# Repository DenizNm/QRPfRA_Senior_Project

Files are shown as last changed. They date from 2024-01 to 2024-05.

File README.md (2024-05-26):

# QRPfRA: Quadruped Robot Platform for Research Applications

## About the Project
This project develops a low-cost, modular quadruped robot to enhance accessibility to robotics education and research. Leveraging the open-source SpotMicro design, the robot is engineered with three degrees of freedom per leg, using readily available servo motors and a Raspberry Pi 4B for computation. It incorporates a 9-DoF IMU and a Raspberry Pi camera for environmental sensing and navigation. The control and processing software, built in Python, utilizes TensorFlow/TFLite and OpenCV for tasks such as motion planning and image processing.

## Features
- **Cost-Effective Design:** Utilizes off-the-shelf components to maintain affordability.
- **Modular and Scalable:** Easy to modify and extend, perfect for educational purposes.
- **Interdisciplinary Approach:** Combines mechanical, electrical, and computer engineering.

## Table of Contents
- [Contact](#contact)
- [Acknowledgements](#acknowledgements)

## Contact
Deniz Namlısesli - [deniz.namlisesli@std.yeditepe.edu.tr](mailto:deniz.namlisesli@std.yeditepe.edu.tr)

Project Link: [https://github.com/DenizNm/QRPfRA_Senior_Project](https://github.com/DenizNm/QRPfRA_Senior_Project)

## Acknowledgements
- [SpotMicro Community](https://spotmicroai.readthedocs.io)
- [TensorFlow](https://tensorflow.org)
- [OpenCV](https://opencv.org)
- All other libraries and frameworks used in this project are acknowledged in the project documentation.

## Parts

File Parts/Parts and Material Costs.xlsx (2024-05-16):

Part | Piece(s) | Total Cost
Raspberry Pi 4B - 8Gb | 1 | ₺2958.75
Raspberry Pi Camera Module 3 | 1 | ₺889.93
MG996R Servo | 12 | ₺882.40
1Kg PLA+ 3D Printer Filament | 1 | ₺445.26
Adafruit BNO055 9-DOF IMU | 1 | ₺1577.56
Custom Designed PCB | 5 | ₺374.92
TAIYO YUDEN TMK316BJ106ML-T Cap, 10Âµf, 25V, 20%, X5r, 1206 | 10 | ₺48.61
TAIYO YUDEN TMK316BBJ226ML-T Capacitor, Mlcc, X5r, 22Uf, 25V, 1206 | 12 | ₺127.37
KEMET C0603C104M5RACTU Cap, 0.1Âµf, 50V, 20%, X7r, 0603 | 10 | ₺8.47
WALSIN WR06X104 JTL Res, 100K, 5%, 0.1W, 0603, Thick Film | 10 | ₺2.22
VISHAY CRCW060352K3FKEA. Res, 52K3, 1%, 0.1W, 0603, Thick Film | 10 | ₺10.70
BOURNS CR0603-FX-1002ELF Res, 10K, 1%, 0.1W, 0603, Thick Film | 10 | ₺4.01
MULTICOMP PRO MCWR06X102 JTL Res, 1K, 5%, 0.1W, 0603, Thick Film | 10 | ₺2.27
TDK VLS6045EX-3R3N Inductor, 3.3Uh, 4.95A, 30%, Wirewound | 5 | ₺70.51
Diodes Inc AP62300Z6-7 DcDc Conv Sync Buck 750Khz 85Deg C | 10 | ₺127.32
Multicomp Pro MP008288 Led Green 90Mcd 577Nm 0603 | 5 | ₺19.40
Multicomp Pro MP011984 Tb Wire To Brd RA 2Way 18Awg | 5 | ₺47.63
Raspberry Pi 2x20 Header Pin | 1 | ₺43.16
1x40 180 Degree Female Header | 1 | ₺5.49
21700 Li-Ion Battery | 3 | ₺960.00
3S 60A BMS | 1 | ₺231.95
 | Total | ₺8837.94

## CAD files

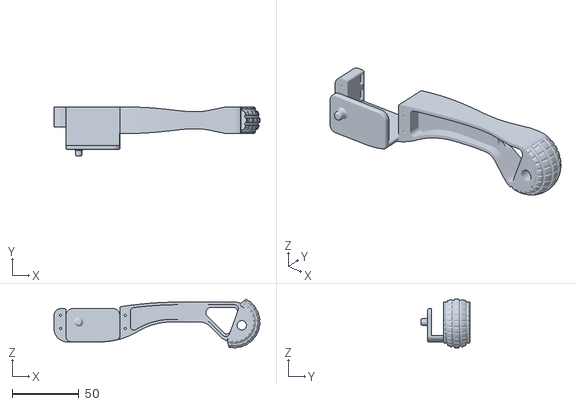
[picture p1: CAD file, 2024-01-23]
QRPfRA/origninal_parts/right_wrist.stl
154.7 x 36.9 x 36.6

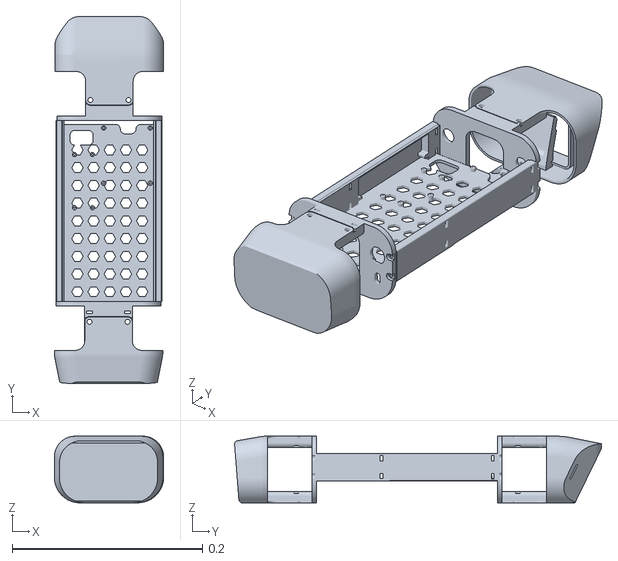
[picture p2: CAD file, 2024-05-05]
QRPfRA/QRPfRA_body_m_extended.stl
0.115 x 0.386 x 0.0701

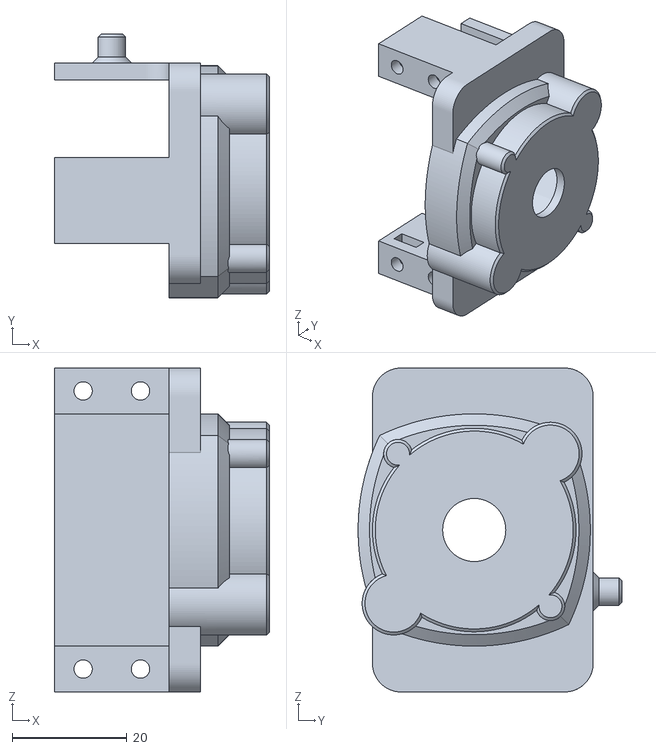
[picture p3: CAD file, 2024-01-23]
QRPfRA/origninal_parts/right_hindlimb.stl
37.5 x 46.0 x 56.5

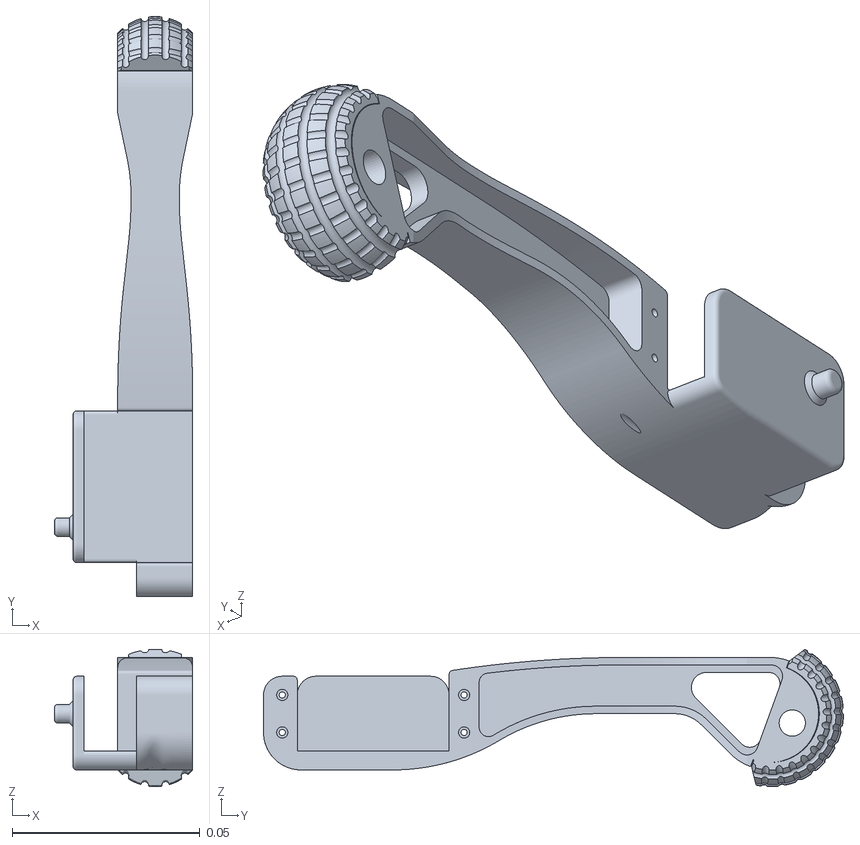
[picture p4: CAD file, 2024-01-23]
QRPfRA/QRPfRA_left_wrist_m.stl
0.0369 x 0.155 x 0.0366

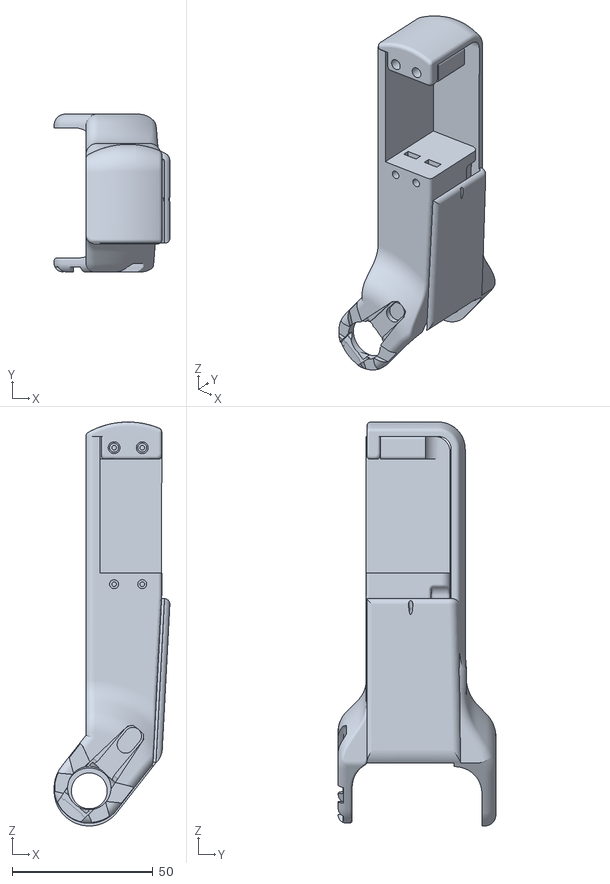
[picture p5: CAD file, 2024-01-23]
QRPfRA/origninal_parts/right_midlimb.stl
41.1 x 56.1 x 143.6

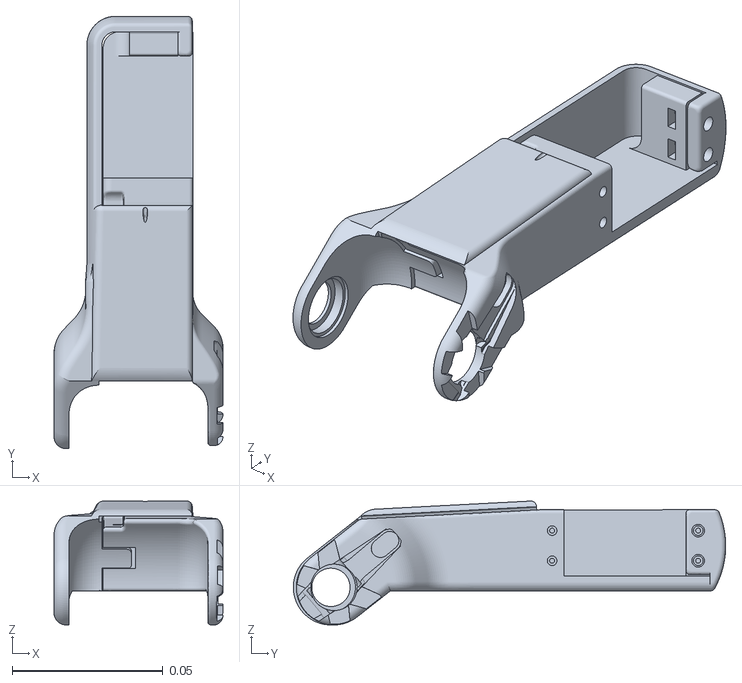
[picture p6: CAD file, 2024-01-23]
QRPfRA/QRPfRA_left_midlimb_m.stl
0.0561 x 0.144 x 0.0411

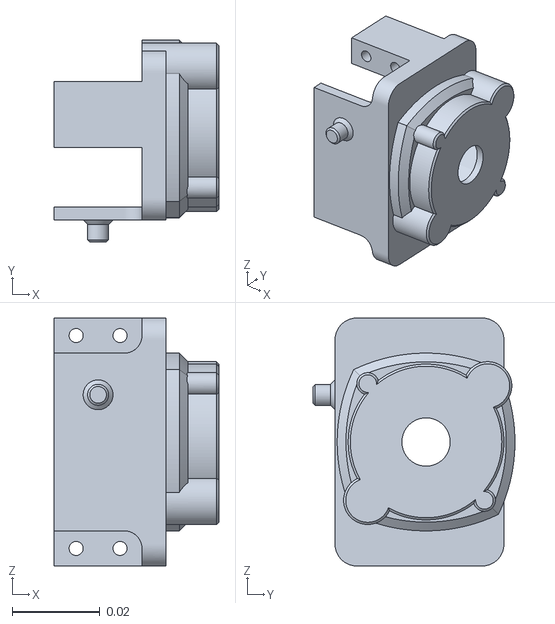
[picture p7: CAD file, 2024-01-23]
QRPfRA/QRPfRA_right_hindlimb_m.stl
0.0375 x 0.046 x 0.0565

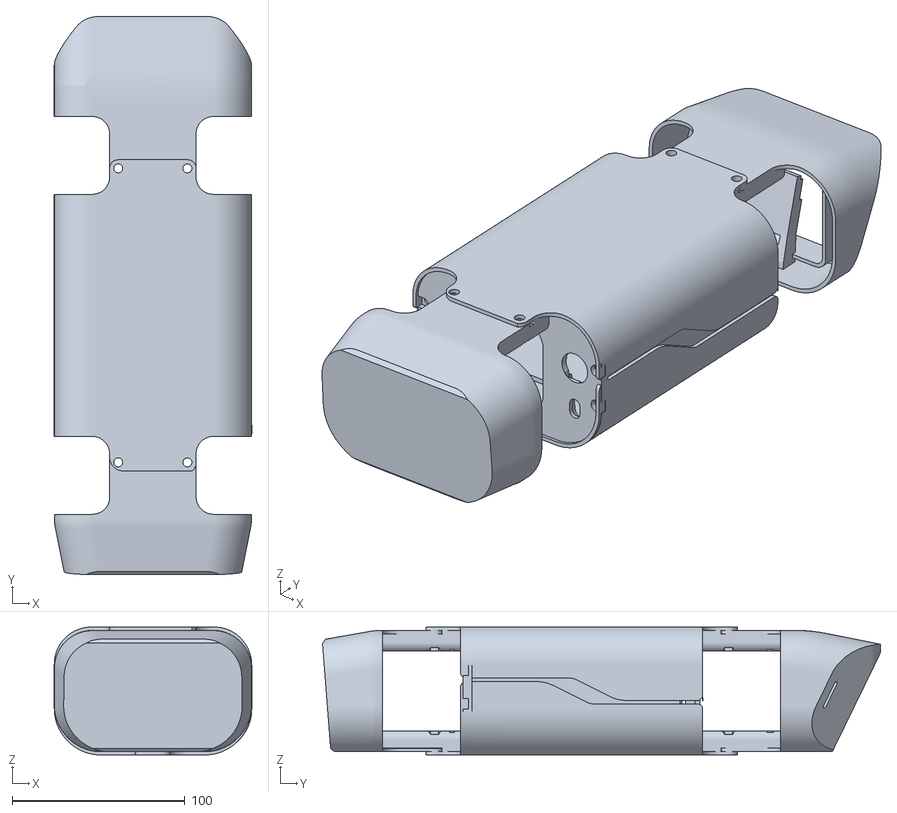
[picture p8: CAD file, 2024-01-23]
QRPfRA/origninal_parts/Body1.stl
114.2 x 322.6 x 74.0

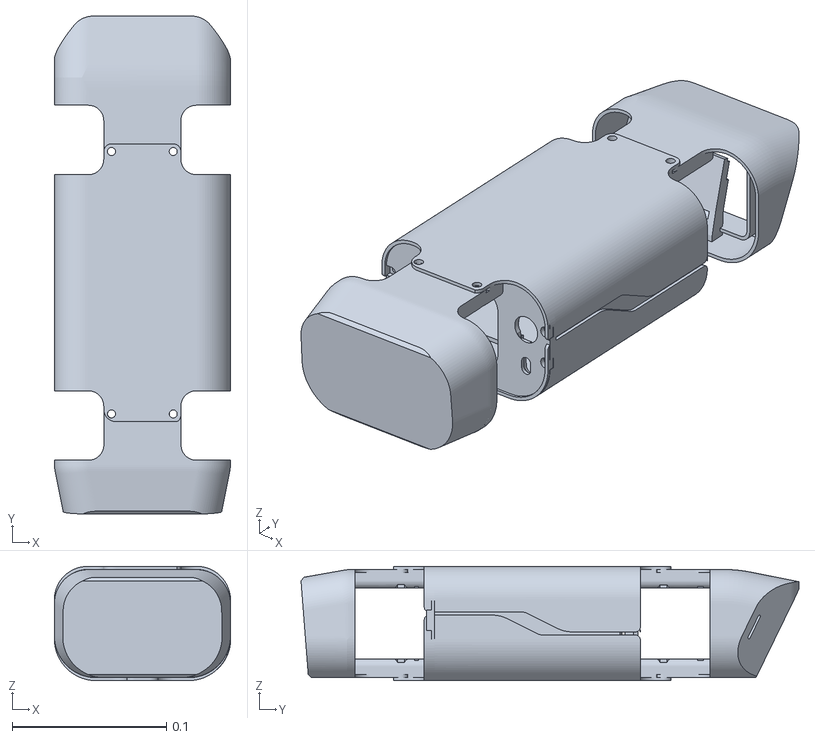
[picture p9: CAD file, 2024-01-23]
QRPfRA/QRPfRA_body_m.stl
0.114 x 0.323 x 0.074

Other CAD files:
QRPfRA/origninal_parts/left_wrist.stl
QRPfRA/origninal_parts/left_hindlimb.stl
QRPfRA/QRPfRA_right_midlimb_m.stl
QRPfRA/origninal_parts/left_midlimb.stl
QRPfRA/QRPfRA_left_hindlimb_m.stl
QRPfRA/QRPfRA_right_wrist_m.stl

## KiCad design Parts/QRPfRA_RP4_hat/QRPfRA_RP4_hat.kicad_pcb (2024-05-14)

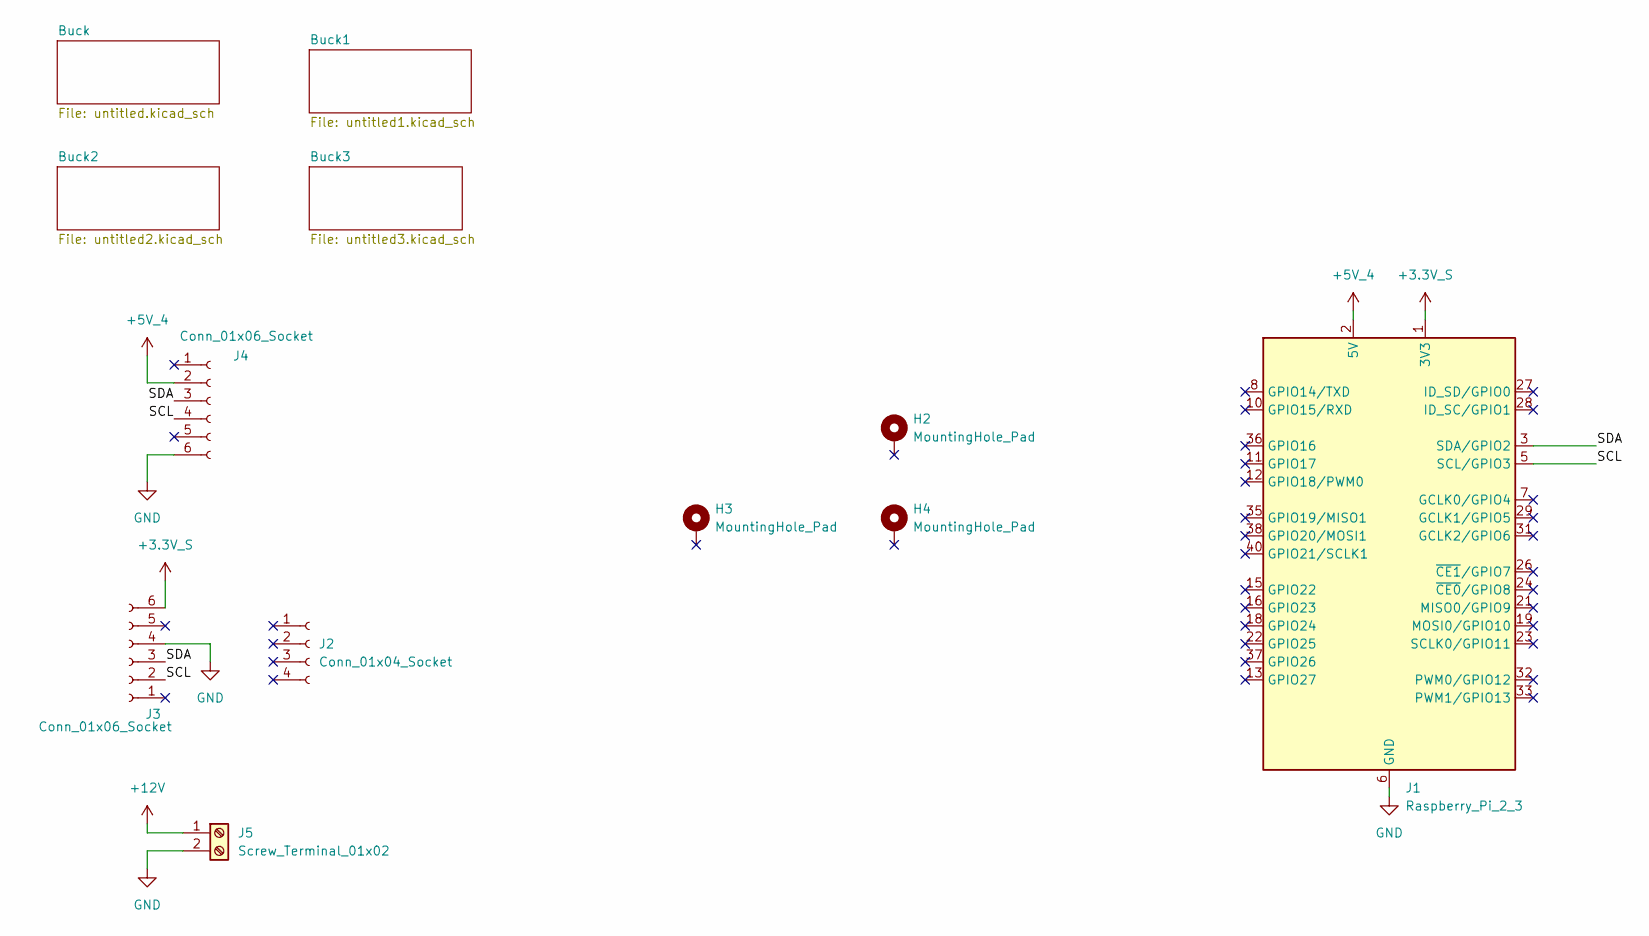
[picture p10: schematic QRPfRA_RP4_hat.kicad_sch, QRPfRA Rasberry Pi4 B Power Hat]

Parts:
H2, H3, H4: MountingHole_Pad; MountingHole_2.7mm_Pad
J1: Raspberry_Pi_2_3; PinHeader_2x20_P2.54mm_Vertical
J2: Conn_01x04_Socket; PinHeader_1x04_P2.54mm_Vertical
J3, J4: Conn_01x06_Socket; PinHeader_1x06_P2.54mm_Vertical
J5: Screw_Terminal_01x02; TerminalBlock_4Ucon_1x02_P3.50mm_Vertical

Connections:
+3.3V_S: J1.1 (3V3), J1.17 (3V3), J3.6
+5V_4: J1.2 (5V), J1.4 (5V), J4.2; also elsewhere on the board
+12V: J5.1; also elsewhere on the board
/SCL: J1.5 (SCL/GPIO3), J3.2, J4.4
/SDA: J1.3 (SDA/GPIO2), J3.3, J4.3
GND: J1.6 (GND), J1.9 (GND), J1.14 (GND), J1.20 (GND), J1.25 (GND), J1.30 (GND), J1.34 (GND), J1.39 (GND), J3.4, J4.6, J5.2; also elsewhere on the board

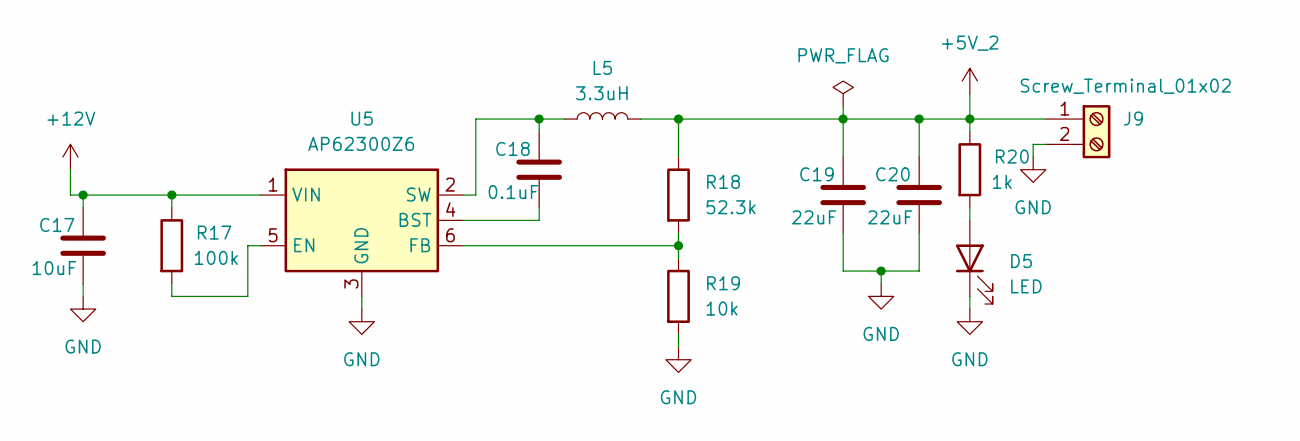
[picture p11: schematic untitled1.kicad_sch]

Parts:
C17: 10uF; C_1206_3216Metric
C18: 0.1uF; C_0603_1608Metric
C19, C20: 22uF; C_1206_3216Metric
D5: LED; LED_0603_1608Metric
J9: Screw_Terminal_01x02; TerminalBlock_4Ucon_1x02_P3.50mm_Vertical
L5: 3.3uH; L_TDK_VLS6045EX_VLS6045AF
R17: 100k; R_0603_1608Metric
R18: 52.3k; R_0603_1608Metric
R19: 10k; R_0603_1608Metric
R20: 1k; R_0603_1608Metric
U5: AP62300Z6; SOT-563

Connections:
+5V_2: C19.1, C20.1, J9.1, L5.2, R18.1, R20.1
+12V: C17.1, R17.1, U5.1 (VIN); also elsewhere on the board
GND: C17.2, C19.2, C20.2, D5.1 (K), J9.2, R19.2, U5.3 (GND); also elsewhere on the board
unnamed: D5.2 (A), R20.2
unnamed: C18.2, U5.4 (BST)
unnamed: R17.2, U5.5 (EN)
unnamed: R18.2, R19.1, U5.6 (FB)
unnamed: C18.1, L5.1, U5.2 (SW)

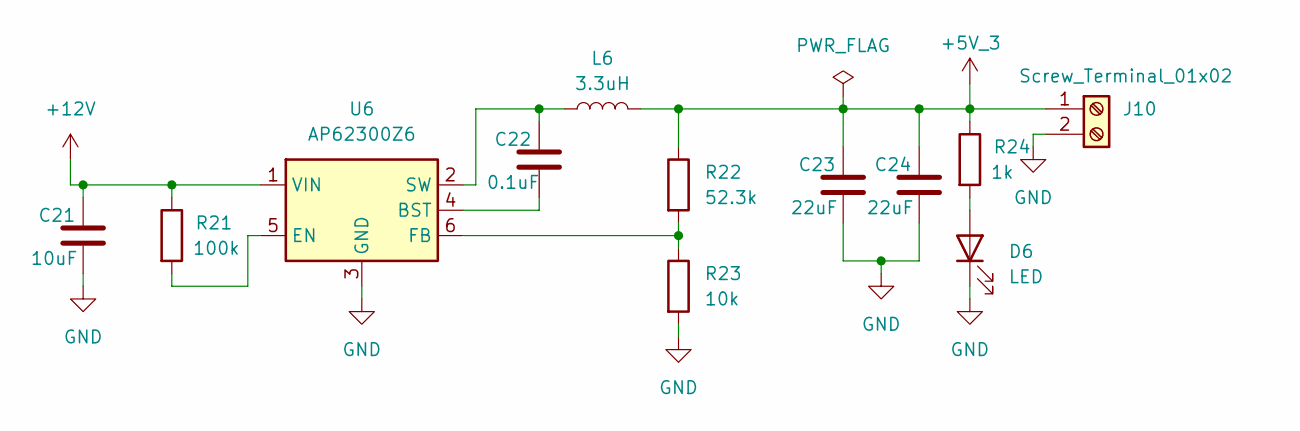
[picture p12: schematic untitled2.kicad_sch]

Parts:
C21: 10uF; C_1206_3216Metric
C22: 0.1uF; C_0603_1608Metric
C23, C24: 22uF; C_1206_3216Metric
D6: LED; LED_0603_1608Metric
J10: Screw_Terminal_01x02; TerminalBlock_4Ucon_1x02_P3.50mm_Vertical
L6: 3.3uH; L_TDK_VLS6045EX_VLS6045AF
R21: 100k; R_0603_1608Metric
R22: 52.3k; R_0603_1608Metric
R23: 10k; R_0603_1608Metric
R24: 1k; R_0603_1608Metric
U6: AP62300Z6; SOT-563

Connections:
+5V_3: C23.1, C24.1, J10.1, L6.2, R22.1, R24.1
+12V: C21.1, R21.1, U6.1 (VIN); also elsewhere on the board
GND: C21.2, C23.2, C24.2, D6.1 (K), J10.2, R23.2, U6.3 (GND); also elsewhere on the board
unnamed: D6.2 (A), R24.2
unnamed: C22.2, U6.4 (BST)
unnamed: R21.2, U6.5 (EN)
unnamed: R22.2, R23.1, U6.6 (FB)
unnamed: C22.1, L6.1, U6.2 (SW)

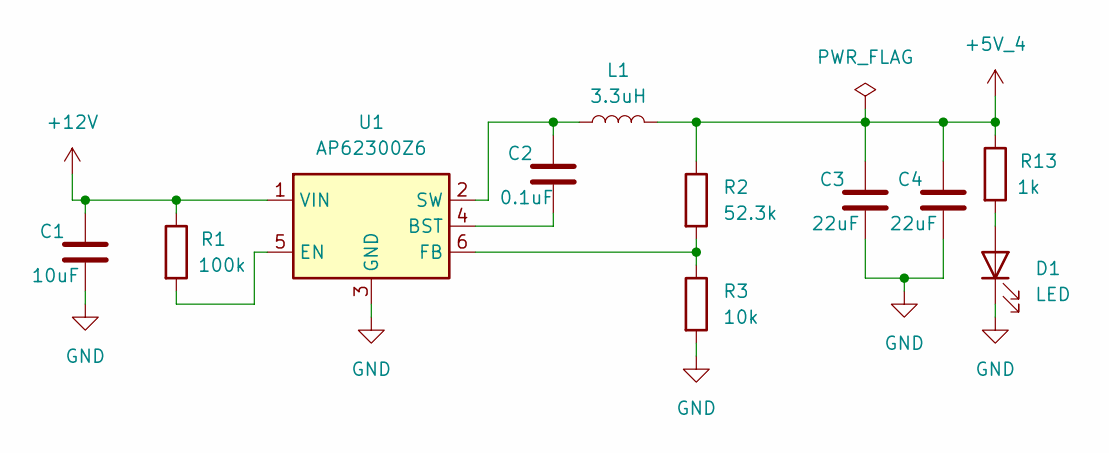
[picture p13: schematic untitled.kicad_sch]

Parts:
C1: 10uF; C_1206_3216Metric
C2: 0.1uF; C_0603_1608Metric
C3, C4: 22uF; C_1206_3216Metric
D1: LED; LED_0603_1608Metric
L1: 3.3uH; L_TDK_VLS6045EX_VLS6045AF
R1: 100k; R_0603_1608Metric
R2: 52.3k; R_0603_1608Metric
R3: 10k; R_0603_1608Metric
R13: 1k; R_0603_1608Metric
U1: AP62300Z6; SOT-563

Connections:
+5V_4: C3.1, C4.1, L1.2, R2.1, R13.1; also elsewhere on the board
+12V: C1.1, R1.1, U1.1 (VIN); also elsewhere on the board
GND: C1.2, C3.2, C4.2, D1.1 (K), R3.2, U1.3 (GND); also elsewhere on the board
unnamed: D1.2 (A), R13.2
unnamed: C2.2, U1.4 (BST)
unnamed: R1.2, U1.5 (EN)
unnamed: R2.2, R3.1, U1.6 (FB)
unnamed: C2.1, L1.1, U1.2 (SW)

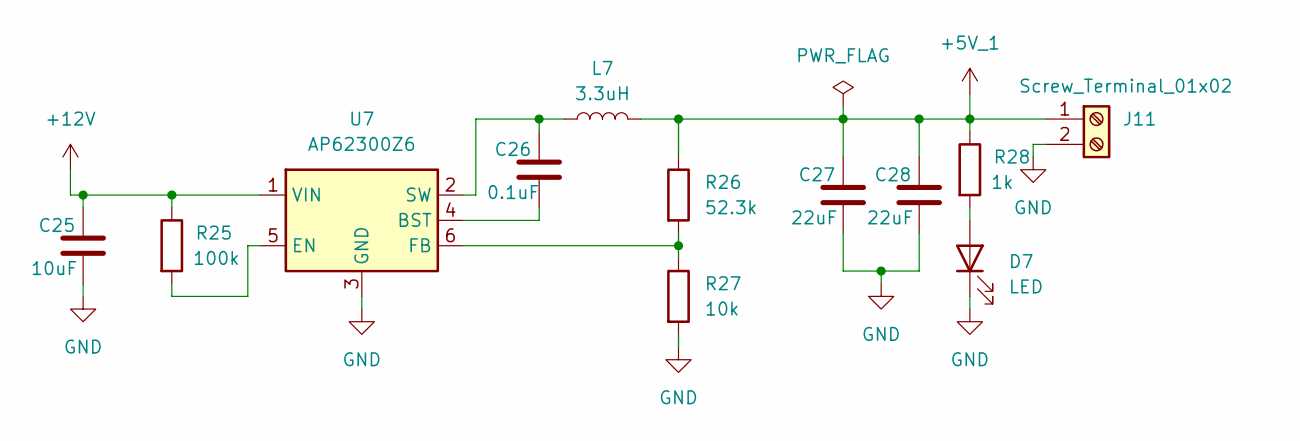
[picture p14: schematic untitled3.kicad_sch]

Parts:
C25: 10uF; C_1206_3216Metric
C26: 0.1uF; C_0603_1608Metric
C27, C28: 22uF; C_1206_3216Metric
D7: LED; LED_0603_1608Metric
J11: Screw_Terminal_01x02; TerminalBlock_4Ucon_1x02_P3.50mm_Vertical
L7: 3.3uH; L_TDK_VLS6045EX_VLS6045AF
R25: 100k; R_0603_1608Metric
R26: 52.3k; R_0603_1608Metric
R27: 10k; R_0603_1608Metric
R28: 1k; R_0603_1608Metric
U7: AP62300Z6; SOT-563

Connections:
+5V_1: C27.1, C28.1, J11.1, L7.2, R26.1, R28.1
+12V: C25.1, R25.1, U7.1 (VIN); also elsewhere on the board
GND: C25.2, C27.2, C28.2, D7.1 (K), J11.2, R27.2, U7.3 (GND); also elsewhere on the board
unnamed: D7.2 (A), R28.2
unnamed: C26.2, U7.4 (BST)
unnamed: R25.2, U7.5 (EN)
unnamed: R26.2, R27.1, U7.6 (FB)
unnamed: C26.1, L7.1, U7.2 (SW)

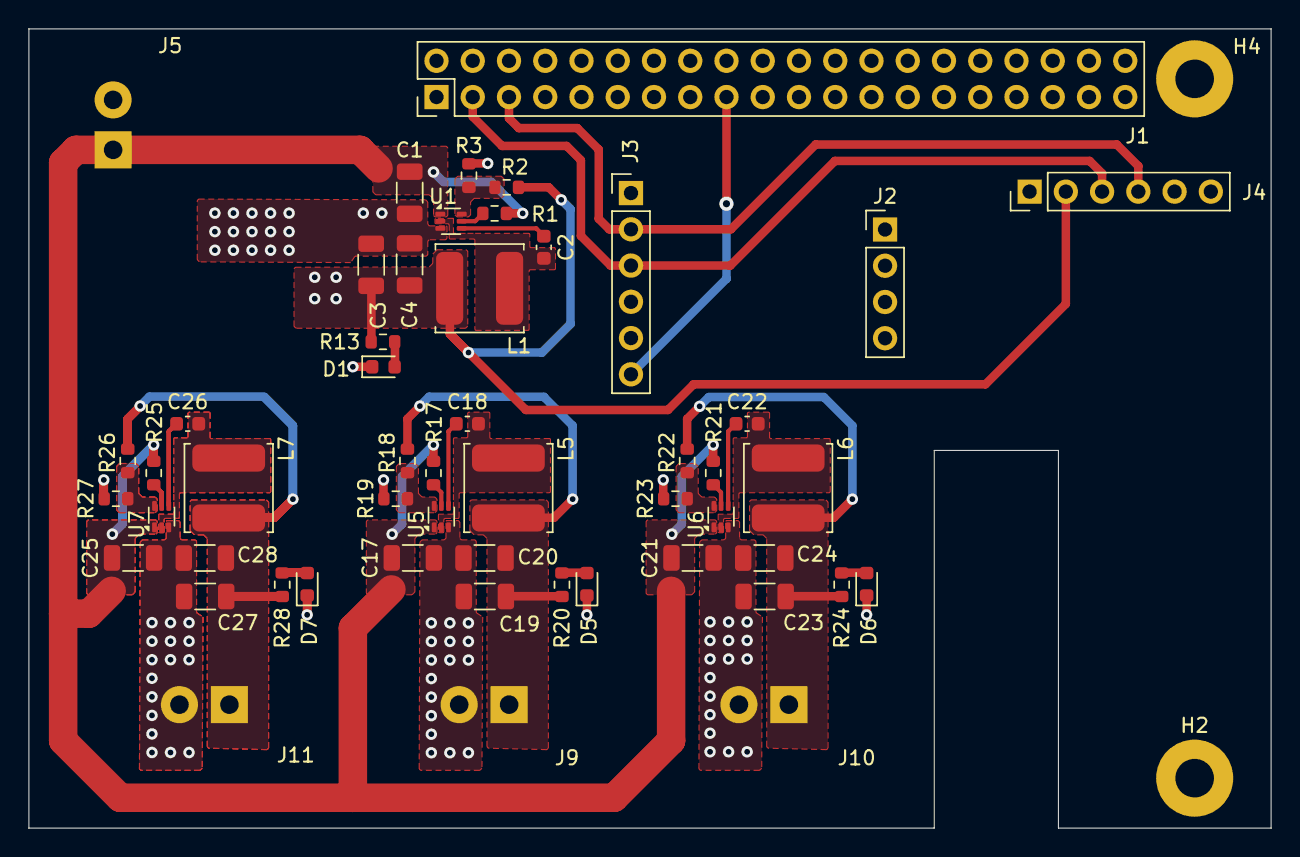
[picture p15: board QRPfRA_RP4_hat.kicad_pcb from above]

Board: 2 copper layers, 87.0 x 56.0 mm, 54 parts (0 on the bottom side), 29 nets.

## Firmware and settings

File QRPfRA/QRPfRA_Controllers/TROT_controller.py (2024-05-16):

import numpy as np
from gymnasium.utils.env_checker import check_env
import QRPfRA
import tensorflow as tf
from scipy.spatial.transform import Rotation as R
import pygame
import os



# Initialize Pygame
pygame.init()
window_size = (640, 480)  # Set this to the resolution of your camera images
screen = pygame.display.set_mode(window_size)
pygame.display.set_caption('QRPfRA Camera View')

#Init QRPfRA environment
env = QRPfRA.QRPfRA_v3(raspberry_pi=False)
check_env(env)
obs = env.reset()

env.render_mode = "human"
env.width = window_size[0]
env.height = window_size[1]



num_states = env.observation_space.shape[0]
print("Size of State Space ->  {}".format(num_states))
num_actions = env.action_space.shape[0]
print("Size of Action Space ->  {}".format(num_actions))

upper_bound = env.action_space.high[0]
lower_bound = env.action_space.low[0]

print("Max Value of Action ->  {}".format(upper_bound))
print("Min Value of Action ->  {}".format(lower_bound))

left_leg_model = tf.lite.Interpreter(model_path=f"{os.path.dirname(os.path.dirname(__file__))}/IK_Models/left_leg_model_quantized.tflite")
right_leg_model = left_leg_model

right_leg_model.allocate_tensors()
left_leg_model.allocate_tensors()

def init_position():
    front_left_leg = np.array([-0.05, 0.0, -0.1])
    back_left_leg = np.array([-0.05, 0.0, -0.105])

    front_right_leg = np.array([-0.05, 0.0, -0.1])
    back_right_leg = np.array([-0.05, 0.0, -0.105])
    return np.concatenate((front_left_leg, back_left_leg, front_right_leg, back_right_leg))


def generate_points(input_list, total_step):
    step_between_points = total_step // (len(input_list) - 1)
    output = []
    for i in range(len(input_list) - 1):
        output.extend(np.linspace(input_list[i], input_list[i + 1], step_between_points))
    return output

def trot_V2(steps=100, reverse=False, fr_height_diff=0.0, left_leg_ctrl=0, right_leg_ctrl=0):
    FL_x = np.ones(4) * -0.05
    FL_y = np.array([(left_leg_ctrl + 0.04), -(left_leg_ctrl + 0.02),  -(left_leg_ctrl + 0.02),  (left_leg_ctrl + 0.04)])
    FL_z = np.array([-(0.15 - left_leg_ctrl/10), -(0.16 + left_leg_ctrl/5), -(0.16 - left_leg_ctrl/5), -(0.13 + left_leg_ctrl/10)])

    RL_x = np.ones(4) * -0.05
    RL_y = np.array([-(left_leg_ctrl + 0.02),  (left_leg_ctrl + 0.04), (left_leg_ctrl + 0.04), -(left_leg_ctrl + 0.02)])
    RL_z = np.array([-(0.16 + left_leg_ctrl/5), -(0.13 - left_leg_ctrl/10), -(0.16 + left_leg_ctrl/5), -(0.15 - left_leg_ctrl/10)]) + fr_height_diff

    FR_x = np.ones(4) * -0.05
    FR_y = np.array([-(right_leg_ctrl+0.02),  (right_leg_ctrl + 0.04), (right_leg_ctrl + 0.04), -(right_leg_ctrl + 0.02)])
    FR_z = np.array([-(0.16 + right_leg_ctrl/5), -(0.13 - right_leg_ctrl/10), -(0.16 + right_leg_ctrl/5), -(0.15 - right_leg_ctrl/10)])

    RR_x = np.ones(4) * -0.05
    RR_y = np.array([(right_leg_ctrl + 0.04),  -(right_leg_ctrl + 0.02), -(right_leg_ctrl + 0.02),  (right_leg_ctrl + 0.04)])
    RR_z = np.array([-(0.15 - right_leg_ctrl/10), -(0.16 + right_leg_ctrl/5), -(0.16 - right_leg_ctrl/5), -(0.13 + right_leg_ctrl/10)]) + fr_height_diff


    if not reverse:
        FL = [FL_x, FL_y, FL_z]
        RL = [RL_x, RL_y, RL_z]
        FR = [FR_x, FR_y, FR_z]
        RR = [RR_x, RR_y, RR_z]
    elif reverse:
        FL = [FL_x, RL_y, FL_z]
        RL = [RL_x, FL_y, RL_z]
        FR = [FR_x, RR_y, FR_z]
        RR = [RR_x, FR_y, RR_z]

    FL_generated = [generate_points(coordination, steps+1) for coordination in FL]
    RL_generated = [generate_points(coordination, steps+1) for coordination in RL]
    FR_generated = [generate_points(coordination, steps+1) for coordination in FR]
    RR_generated = [generate_points(coordination, steps+1) for coordination in RR]

    FL_generated[:][0] = np.clip(FL_generated[:][0], -0.09, 0.01)
    RL_generated[:][0] = np.clip(RL_generated[:][0], -0.09, 0.01)
    FR_generated[:][0] = np.clip(FR_generated[:][0], -0.09, 0.01)
    RR_generated[:][0] = np.clip(RR_generated[:][0], -0.09, 0.01)

    FL_generated[:][1] = np.clip(FL_generated[:][1], -0.06, 0.06)
    RL_generated[:][1] = np.clip(RL_generated[:][1], -0.06, 0.06)
    FR_generated[:][1] = np.clip(FR_generated[:][1], -0.06, 0.06)
    RR_generated[:][1] = np.clip(RR_generated[:][1], -0.06, 0.06)

    FL_generated[:][2] = np.clip(FL_generated[:][2], -0.195, -0.06)
    RL_generated[:][2] = np.clip(RL_generated[:][2], -0.195, -0.06)
    FR_generated[:][2] = np.clip(FR_generated[:][2], -0.195, -0.06)
    RR_generated[:][2] = np.clip(RR_generated[:][2], -0.195, -0.06)

    foot_list = np.concatenate((FL_generated, RL_generated, FR_generated, RR_generated)).T

    return foot_list



def _run_inference(model, input_data):
    input_details = model.get_input_details()
    output_details = model.get_output_details()

    input_data = np.array(input_data, dtype=np.float32).reshape(1, -1)

    model.set_tensor(input_details[0]['index'], input_data)
    model.invoke()
    output_data = model.get_tensor(output_details[0]['index'])
    return output_data

def phase_transition_controller(act_in, act_out):
    err = act_out - act_in
    action = act_in + 0.10 * err
    return action


def action_xyz_to_angle(action_xyz, current_action_angle):
    if type(action_xyz) != list:
        action_xyz = action_xyz.tolist()
    elif type(action_xyz) == list:
        pass
    else:
        raise ValueError("Invalid data type for action_xyz")

    FL = _run_inference(left_leg_model, action_xyz[0:3])
    RL = _run_inference(left_leg_model, action_xyz[3:6])

    FR = _run_inference(right_leg_model, action_xyz[6:9])
    RR = _run_inference(right_leg_model, action_xyz[9:12])

    action_angle = np.array([FL, RL, FR, RR]).flatten()

    action_angle = phase_transition_controller(current_action_angle, action_angle)
    return action_angle


def get_orientation(observation):
    rotation = R.from_quat(observation[21:])
    coordinates = "YZX"
    euler_angles = rotation.as_euler(coordinates, degrees=True)
    if euler_angles[2] <= 0:
        euler_angles[2] = -(euler_angles[2] + 180)
    else:
        euler_angles[2] = 180 - euler_angles[2]

    control_y_direction = euler_angles[2]
    return control_y_direction

def update_y_list(y_list, y):
    y_list = np.roll(y_list, 1)
    y_list[0] = y
    return y_list, np.mean(y_list)


current_action_angle = np.zeros(12).flatten()
step = 0
left_leg_ctrl = 0.0
right_leg_ctrl = 0.0

total_steps = 100
generated_action = trot_V2(total_steps, reverse=False, fr_height_diff=0.02, left_leg_ctrl=0.0, right_leg_ctrl=0.0)

prev_y_list = np.zeros(5)
current_observations = np.zeros(num_states)
in_step_cnt = 0

desired = 0
init_pos = False



while True:
    for event in pygame.event.get():
        if event.type == pygame.QUIT:
            pygame.quit()
            quit()
    keys = pygame.key.get_pressed()

    if keys[pygame.K_p]:
        if init_pos:
            init_pos = False
        else:
            init_pos = True

    if step > 100 and not init_pos:
        action_xyz = generated_action[in_step_cnt, :]
        if in_step_cnt == (total_steps-2):
            in_step_cnt = 0

        in_step_cnt += 1

        control_y_direction = get_orientation(current_observations)
        prev_y_list, mean_y_direction = update_y_list(prev_y_list, control_y_direction)

        # Adjust desired angle using keyboard input from A and G keys
        if keys[pygame.K_a]:
            desired += 1
        if keys[pygame.K_g]:
            desired -= 1

        # make desired angle -180 after 180 and vice versa centered around 0
        desired = np.clip(desired, -178, 178)
        print(f"Desired: {desired}, Control y direction: {mean_y_direction}")

        error = (mean_y_direction - desired) * 0.0016
        if error > 0:
            generated_action = trot_V2(total_steps, reverse=False, fr_height_diff=-0.02,
                                               left_leg_ctrl=abs(error), right_leg_ctrl=-0.8 * abs(error))
        else:
            generated_action = trot_V2(total_steps, reverse=False, fr_height_diff=-0.02,
                                               left_leg_ctrl=-0.8 * abs(error), right_leg_ctrl= abs(error))

    elif step <= 100 or init_pos:
        action_xyz = init_position()


    
    action_angle = action_xyz_to_angle(action_xyz, current_action_angle)
    obs, reward, done, _, info = env.step(action_angle)
    current_action_angle = action_angle
    current_observations = obs


    if env.render_mode != "human":
        image = env.get_rgb_and_depth_image()
        if env.render_mode == "rgb_array":
            rgb_image_pygame = pygame.surfarray.make_surface(np.transpose(image, (1, 0, 2)))
            screen.blit(rgb_image_pygame, (0, 0))
        elif env.render_mode == "depth_array":
            depth_image = image * 100
            depth_image_grayscale = np.repeat(depth_image[:, :, np.newaxis], 3, axis=2)
            depth_image_surface = pygame.surfarray.make_surface(np.transpose(depth_image_grayscale, (1, 0, 2)))
            screen.blit(depth_image_surface, (0, 0))
        else:
            raise ValueError("Invalid render mode, choose either 'rgb_array' or 'depth_array'")

        pygame.display.update()
    else:
        pygame.display.update()
        pass


    if done:
        env.reset()

    step += 1

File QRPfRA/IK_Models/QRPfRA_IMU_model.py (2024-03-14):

import numpy as np
from gymnasium import utils
from gymnasium.envs.mujoco import MujocoEnv
from gymnasium.error import Error
from gymnasium.spaces import Box
from gymnasium.utils.env_checker import check_env
import tensorflow as tf
from QRPfRA_IMU import QRPfRA_v3

import numpy as np
from gymnasium import utils
from gymnasium.envs.mujoco import MujocoEnv
from gymnasium.error import Error
from gymnasium.spaces import Box
from gymnasium.utils.env_checker import check_env
import tensorflow as tf
import os
import serial as pyserial
from scipy.spatial.transform import Rotation as R


class QRPfRA_v3(MujocoEnv, utils.EzPickle):
    metadata = {
        "render_modes": [
            "human",
            "rgb_array",
            "depth_array",
        ],
    }

    def __init__(self,
                 xml_file="/Users/deniz/PycharmProjects/QRPfRA_Senior_Project/QRPfRA/IK_Models/qrpfra_v3_scene_IMU.xml",
                 frame_skip=1, use_serial_port=False, **kwargs):

        utils.EzPickle.__init__(self, xml_file, frame_skip, **kwargs)
        MujocoEnv.__init__(
            self,
            xml_file,
            frame_skip=frame_skip,
            observation_space=None,  # needs to be defined after
            default_camera_config={},
            **kwargs,
        )

        self.metadata = {
            "render_modes": [
                "human",
                "rgb_array",
                "depth_array",
            ],
            "render_fps": int(np.round(1.0 / self.dt)),
        }

        obs_size = len(self.data.sensordata.flat.copy())
        self.step_count = 0

        self.observation_space = Box(
            low=-np.inf, high=np.inf, shape=(obs_size,), dtype=np.float64
        )

        self.use_serial_port = use_serial_port

        if self.use_serial_port:
            self.serial_port = pyserial.Serial('/dev/tty.usbserial-1110', 9600)
            if not self.serial_port.is_open:
                self.serial_port.open()

    def step(self, action):
        # Uncomment to run inference for TFlite inverse kinematics models

        # Action is between -1 and 1

        if self.use_serial_port:
            self.sent_over_serial(action)

        self.do_simulation(action, self.frame_skip)
        observation = self._get_obs()
        # print(observation)

        rotation = R.from_quat(observation[27:])
        # print(rotation)
        coordinates = "YZX"
        euler_angles = rotation.as_euler(coordinates, degrees=True)
        if euler_angles[2] <= 0:
            euler_angles[2] = -(euler_angles[2] + 180)
        else:
            euler_angles[2] = 180 - euler_angles[2]

        # print(f"Euler Angles ({coordinates}):", euler_angles)

        reward = self._compute_reward(observation, action) - 100
        info = {}

        if self.render_mode == "human":
            self.render()

        done = False

        reward = int(reward)
        # print("Reward:", reward)

        # obs = np.concatenate(np.array(observation[0:6]), np.array(euler_angles))
        # print("environment observation:", obs)

        return observation, euler_angles, reward, done, False, info  # done, false, info

    def _get_obs(self):
        sensor_data = self.data.sensordata.flat.copy()
        sensor_data[23:27] = [1.0 if i > 0.0 else 0.0 for i in sensor_data[23:27]]

        return sensor_data

    def _unionize_action_buffer(self, action_buffer):
        """ each degree must consists of 3 integers totaling 36 integers, if an incoming angle for eaxmple 72,
         it must be converted to 072 rounded to 3 integers. """
        return [f"{angle:03d}" for angle in action_buffer]

    def sent_over_serial(self, action):
        action_to_send = action * 60 + 60
        action_to_send = np.clip(action_to_send, 0, 120)
        action_to_send[1:3] = 120 - action_to_send[1:3]
        action_to_send[4:6] = 120 - action_to_send[4:6]
        action_to_send = action_to_send.astype(np.uint8)
        action_to_send = self._unionize_action_buffer(action_to_send)
        # print("Action:", action_to_send)

        action_to_send = ''.join(map(str, action_to_send))  # Convert list to string
        print("Action to send:", action_to_send)
        action_to_send = action_to_send.encode()  # Encode string to bytes
        self.serial_port.write(action_to_send)  # Write bytes to serial port
        # msg = self.serial_port.read(1)
        # print("Message:", msg.decode('utf-8'))

    def reset_model(self):
        qpos = self.init_qpos
        qvel = self.init_qvel
        self.set_state(qpos, qvel)

        observation = self._get_obs()
        self.step_count = 0
        return observation

    def _get_reset_info(self):
        return {"works": True}

    def _compute_reward(self, observation, action):
        # Get absolute position of the base
        baselink_pos = self.get_body_com("base_link")
        FL_hind_limb = observation[9]
        RL_hind_limb = observation[12]
        FR_hind_limb = observation[15]
        RR_hind_limb = observation[18]
        foot_observation = sum(observation[23:27])

        x, y, z = tuple(baselink_pos)

        reward = (y * 10) ** 3 - abs(x) * 10

        if (0.2 < observation[21] or observation[21] == -1 and
                0.2 < observation[22] or observation[22] == -1):
            reward += 10
        else:
            reward -= 10

        if FL_hind_limb < 0 or RL_hind_limb < 0 or FR_hind_limb > 0 or RR_hind_limb > 0:
            reward -= 10000

        if foot_observation >= 3:
            reward += foot_observation * 50
        else:
            reward -= 1500

        if observation[2] < -4 and self.step_count > 100:
            reward -= 50000

        return reward


env = QRPfRA_v3()
obs = env.reset_model()
print(obs)


right_leg_model = tf.lite.Interpreter(model_path='/Users/deniz/PycharmProjects/QRPfRA_Senior_Project/QRPfRA/IK_Models/left_leg_model_quantized.tflite')
right_leg_model.allocate_tensors()

left_leg_model = tf.lite.Interpreter(model_path='/Users/deniz/PycharmProjects/QRPfRA_Senior_Project/QRPfRA/IK_Models/left_leg_model_quantized.tflite')
left_leg_model.allocate_tensors()


def init_position():
    front_left_leg = np.array([-0.05, 0.0, -0.1])
    back_left_leg = np.array([-0.05, 0.0, -0.105])

    front_right_leg = np.array([-0.05, 0.0, -0.1])
    back_right_leg = np.array([-0.05, 0.0, -0.105])
    return np.concatenate((front_left_leg, back_left_leg, front_right_leg, back_right_leg))


def second_pose():
    front_left_leg = np.array([-0.15, 0, -0.12])
    back_left_leg = np.array([-0.15, 0, -0.125])

    front_right_leg = np.array([0.15, 0, -0.12])
    back_right_leg = np.array([0.15, 0, -0.125])
    return np.concatenate((front_left_leg, back_left_leg, front_right_leg, back_right_leg))
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

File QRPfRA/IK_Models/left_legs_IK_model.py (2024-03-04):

import os
import warnings

import numpy as np
import pytest

from gymnasium import utils
from gymnasium.envs.mujoco import MujocoEnv
from gymnasium.error import Error
from gymnasium.spaces import Box
from gymnasium.utils.env_checker import check_env

import tensorflow as tf
from tensorflow import keras


leg_interpreter = tf.lite.Interpreter(model_path='/Users/deniz/PycharmProjects/QRPfRA_Senior_Project/QRPfRA/IK_Models/left_leg_model_quantized.tflite')
leg_interpreter.allocate_tensors()


class QRPfRA_v3(MujocoEnv, utils.EzPickle):
    metadata = {
        "render_modes": [
            "human",
            "rgb_array",
            "depth_array",
        ],
    }

    def __init__(self, xml_file="/Users/deniz/PycharmProjects/QRPfRA_Senior_Project/QRPfRA/IK_Models/qrpfra_v3_leg_ik_scene_left.xml", frame_skip=1, **kwargs):
        utils.EzPickle.__init__(self, xml_file, frame_skip, **kwargs)

        MujocoEnv.__init__(
            self,
            xml_file,
            frame_skip=frame_skip,
            observation_space=None,  # needs to be defined after
            default_camera_config={},
            **kwargs,
        )

        self.metadata = {
            "render_modes": [
                "human",
                "rgb_array",
                "depth_array",
            ],
            "render_fps": int(np.round(1.0 / self.dt)),
        }

        obs_size = self.data.qpos.size + self.data.qvel.size

        self.observation_space = Box(
            low=-np.inf, high=np.inf, shape=(obs_size,), dtype=np.float64
        )
        self.left_leg_model = leg_interpreter

    def step(self, action):
        print("Position of the foothold", action)
        #x_position_before = self.data.qpos[0]
        action = np.array(action).reshape(1, 3)
        action = self._run_inference(self.left_leg_model, action)[0]*100

        print("Angle action", action)

        self.do_simulation(action, self.frame_skip)
        #x_position_after = self.data.qpos[0]

        observation = self._get_obs()
        reward = 0  #x_position_after - x_position_before
        info = {}

        if self.render_mode == "human":
            self.render()

        return observation, reward, False, False, info

    def _get_obs(self):
        #position = self.data.qpos.flat.copy()
        #velocity = self.data.qvel.flat.copy()
        sensor_data = self.data.sensordata.flat.copy()

        return sensor_data

    def reset_model(self):
        qpos = self.init_qpos
        qvel = self.init_qvel
        self.set_state(qpos, qvel)

        observation = self._get_obs()

        return observation

    def _get_reset_info(self):
        return {"works": True}


    def _run_inference(self, model, input_data):
        input_details = model.get_input_details()
        output_details = model.get_output_details()

        input_data = np.array(input_data, dtype=np.float32)

        model.set_tensor(input_details[0]['index'], input_data)
        model.invoke()
        output_data = model.get_tensor(output_details[0]['index'])
        return output_data



env = QRPfRA_v3()
check_env(env)
obs = env.reset()
env.render_mode = "human"

for i in range(10000000):
    for i in range(-120, 120):

        obs, reward, done, _, info = env.step([float(m) for m in [-0.05, i/1000, -0.16]])
    for i in range(120, -120, -1):
        #action = env.action_space.sample()
        obs, reward, done, _, info = env.step([float(m) for m in [-0.05, i/1000, -0.16]])

env.close()

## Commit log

2024-01-23 Initial commit of MuJoCo definition for SpotMicro body
    [Body1.stl, QRPfRA_body_m.stl, QRPfRA_left_hindlimb_m.stl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]
2024-01-25 Part costs, left leg IK model and scene definition
    [Parts and Material Costs.xlsx]
2024-01-26 Left leg IK model update, Right leg IK model added with necessary xml and notebook files
2024-02-01 Right IK model is working correctly, left leg IK model must be fixed
    [QRPfRA.py, tf_2_TFlite.py]
2024-02-04 Right legs hindlimb axis changed
2024-05-02 New TROT controller added, ultrasonic range sensors removed
2024-05-05 Extended body mes is added alongside modified scene and model definition files
    [QRPfRA_body_m_extended.stl]
2024-05-06 Raspberry Pi 4 Power-Servo-IMU Hat KiCad Files
    [QRPfRA_RP4_hat-B_Cu.gbr, QRPfRA_RP4_hat-B_Mask.gbr, QRPfRA_RP4_hat-B_Paste.gbr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]
2024-05-12 Table Updated
    [Parts and Material Costs.xlsx]
2024-05-14 Updated cost list, changes to QRPfRA class, and modifications on TROT_controller.py
    [Parts and Material Costs.xlsx]
2024-05-16 Modification to XML models
    [Parts and Material Costs.xlsx]
